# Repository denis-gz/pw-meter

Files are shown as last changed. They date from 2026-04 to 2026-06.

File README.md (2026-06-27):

# PW Meter - EMB_1 Graduation Project

Splash Screen

## Power Meter - An appliance to measure and log AC power line parameters

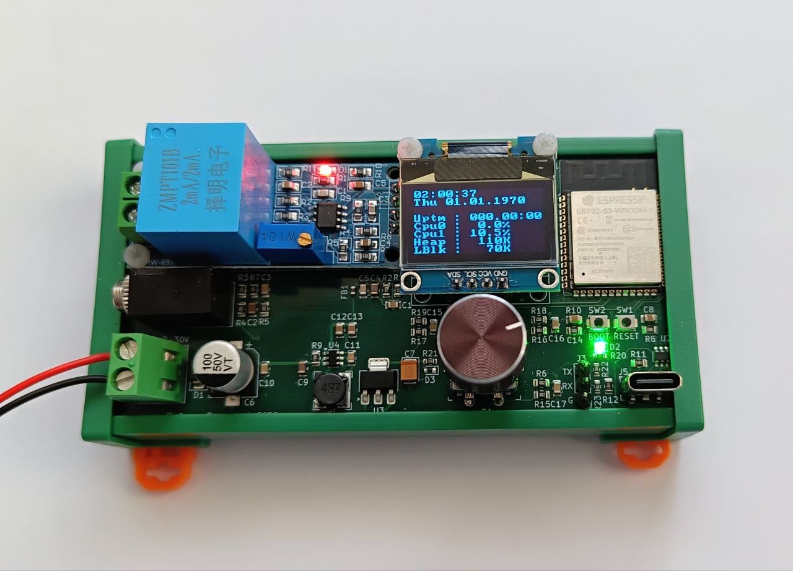
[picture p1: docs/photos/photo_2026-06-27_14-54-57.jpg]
Production sample


The Power Meter can be attached to the AC mains load to measure the following parameters:

 - **AC Voltage** (V, RMS)
 - **AC Current** (A, RMS)
 - **Instantaneous active power** (W)
 - **Instantaneous apparent power** (VA)
 - **Accumulated energy** (Wh)
 - **Power factor** (W/VA ratio)
 - **AC frequency** (Hz)

## Quick Start

In case you have assembled the board using the schematic and components specified in the KiCad project, follow these steps to bring it to life:

1. You may use the supplied firmware image or build your own. If building from source, please update `mqtt_creds.h` and `wifi_creds.h` files with your credentials (not necessary if you do not require MQTT telemetry). Also, please verify settings in the `sdkconfig` to match actual hardware (since at the time of this writing the project has not yet been tested with the actual/final PCB). Use usual `idf.py menuconfig` command to re-generate the `sdkconfig`. See also [defconfig.bak](defconfig.bak) file for exact set of parameters used to configure the project.
2. To build the firmware image, use standard **ESP-IDF** tools (CMake, idf.py, etc). Look [here](https://docs.espressif.com/projects/esp-idf/en/v5.5.4/esp32/api-guides/build-system.html) for a reference.
3. Flash the firmware via USB Serial/JTAG interface (hold the **BOOT** key while powering on the board). The ESP32's **UART0** interface is also available on the **J3** header for flashing or serial console access (useful for adjusting parameters at runtime).
4. Connect the AC voltage source to the Voltage Transformer module (**U6** sub-board).
5. Pass the **Live** wire of the AC load through the core of the Current Transformer (**SCT013-100** or similar). For low-power loads, wrap the wire around the transformer core several times to amplify the signal. Alternatively, use a sensor with a lower current range. If your sensor includes an internal burden resistor, you may need to desolder the **R3** resistor from the board. Connect the Current Transformer to the **J2** socket. It is also possible to use the PW Meter without a load; in this case, set the `I noise floor` parameter high enough to prevent bogus readings.
6. Connect a **7-30V DC** power source to the **J1** socket. The board itself should not consume more than 5 Watts.
7. The Power Meter starts working immediately, displaying data on the OLED display.
8. Use the **Encoder** to switch pages. Use the Encoder's **push-button** to pause/resume on the Mains page, or to enter the menu on the Settings page. Use a **long press** (> 0.5 sec) to return to the upper level. Performing a long press while at the top level will restart the app. Use the **RES** key for a hard reset.

## Project Structure

### Hardware

The project consists of a main board and two sub-boards:
* **Voltage Transformer:** HW-697 Single-phase AC Active Output Voltage Transformer by LC Technology.
* **Display:** SSD1315 128x64 monochrome I2C OLED (GM009605). Any other SSD1306 I2C compatible display should also work (check the module's address in `idf.py menuconfig`).

Sampling of AC voltage and current channels occur in DMA continuous mode, the rate is 4 kHz per channel, with 12 bit resolution and 11.5 dB attenuation. The samples are then adjusted for non-linearity using pre-calibrated curves, centered at 0 level, and processed using DSP capabilities of ESP32-S3 chip. Employing hardware acceleration helps keep CPU usage reasonably low (~10% on Core 1, or only 5% without display output).

Please find further details on project's [Schematic](docs/hardware/Schematic_R1.pdf), and PCB board views ([Top Layer](docs/hardware/PcbTop.png), [Inner 1](docs/hardware/PcbInner1.png), [Inner 2](docs/hardware/PcbInner2.png), [Bottom Layer](docs/hardware/PcbBottom.png) and [3D View](docs/hardware/jlcpcb_3d_1.png)).

### Software

The software consists of 5 tasks:

* `reader_task`: ADC sampling task. Performs reading, parsing and adjustment of analog data. Outputs raw values in mV to a ring buffer for the Compute Task.
* `compute_task`: Processes data in 10-cycle chunks. Performs all mathematical calculations and outputs results to the queue for the Interface Task.
* `interface_task`: Applies filtering, updates the OLED display, handles user input from the rotary encoder and console. Sends a copy of the UI data to the Telemetry Task.
* `telemetry_task`: Maintains Wi-Fi and MQTT connections and publishes data to the MQTT broker.
* `console_input_task`: A service task created by the console event loop that handles prompts and waits for user input from the UART console.

The `PowerMeterApp` class represents the main class which initializes all tasks and waits for a stop event. It handles task shutdown, and the `app_main()` function recreates the instance if needed.

## Signal Path

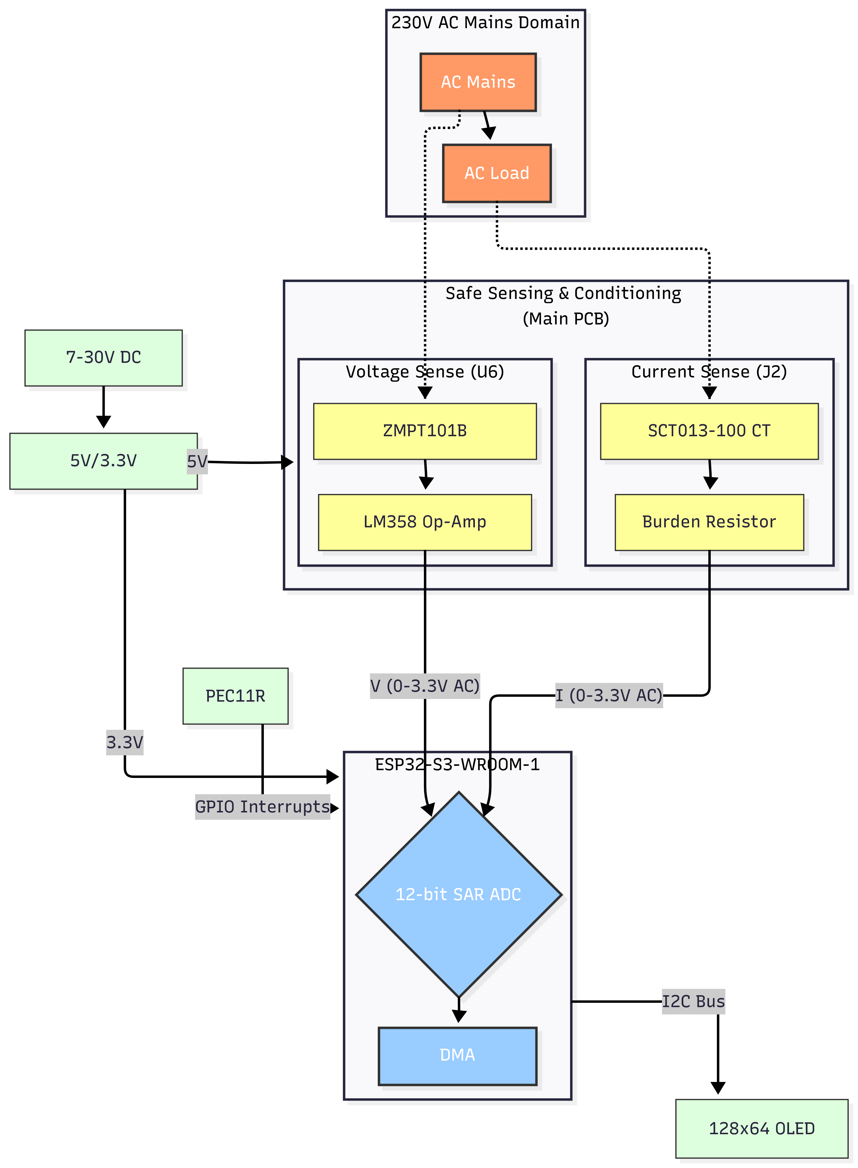
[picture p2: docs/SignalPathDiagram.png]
Signal Path


## Data Flow

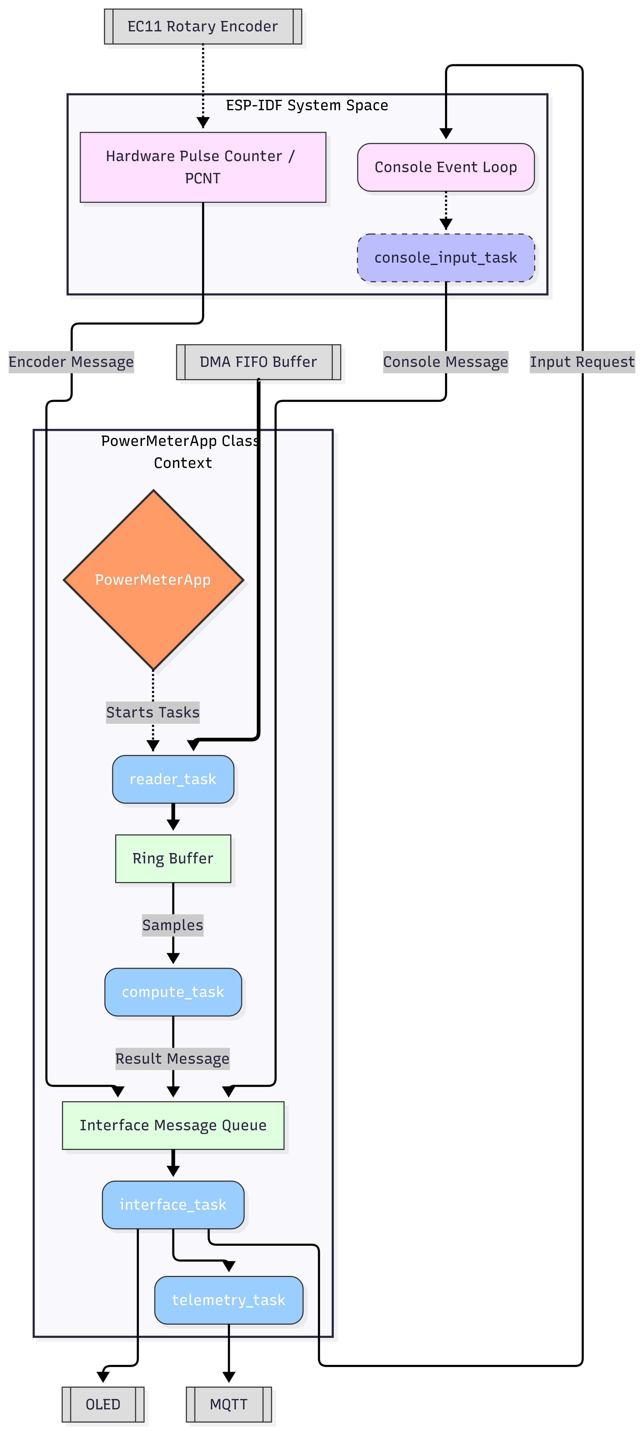
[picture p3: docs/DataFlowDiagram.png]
Data Flow


## Technology

* **MCU:** Espressif ESP32-S3-WROOM-1 N16R2 module
* **AC Voltage Input:** [HW-697](http://www.chinalctech.com/cpzx/Programmer/Sensor_Module/250.html) module by LC Tech (ZMPT101B transformer paired with an LM358 op-amp)
* **AC Current Input:** [SCT013-100](http://en.yhdc.com/comp/file/download.do?id=941) Split-core current transformer (100A, 2000:1 ratio)
* **Display:** GM009605 OLED module based on SSD1306 controller (I2C bus) (or similar)
* **Input:** EC11 rotary encoder
* **Debugging:** BOOT and RESET buttons, UART, and USB Type-C JTAG/Serial ports
* **Software:** ESP-IDF v5.5.4-based CMake project, developed with QtCreator v18.0.2
* **Third-party components:**
    * `nopnop2002/ssd1306`: OLED display support
* **PCB:** 4-layer FR-4 PCB (100x50 mm), developed in KiCad 9.0.7. Mostly uses SMT components (0805 and 0603).

## Example Output

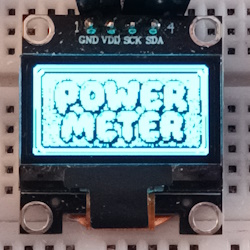
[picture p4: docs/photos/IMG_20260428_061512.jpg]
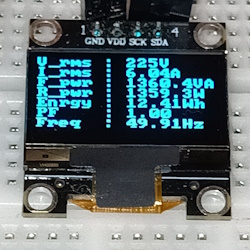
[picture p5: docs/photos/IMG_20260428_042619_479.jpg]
Mains Page
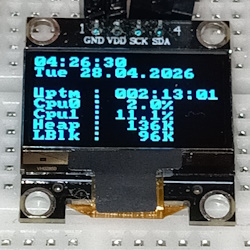
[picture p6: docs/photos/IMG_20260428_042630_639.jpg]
Device Page
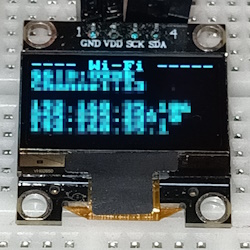
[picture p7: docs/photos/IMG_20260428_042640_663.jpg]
Network Page
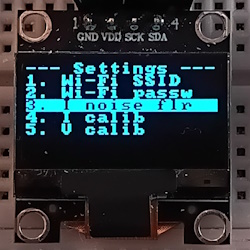
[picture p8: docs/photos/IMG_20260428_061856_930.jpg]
Settings Page
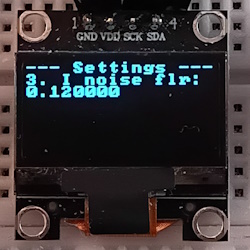
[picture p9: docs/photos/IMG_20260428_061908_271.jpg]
Parameter Page
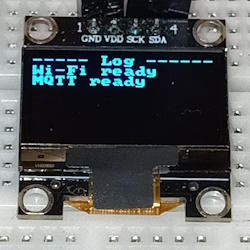
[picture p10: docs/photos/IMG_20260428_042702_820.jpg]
Log Page
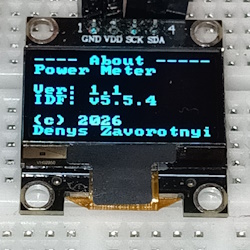
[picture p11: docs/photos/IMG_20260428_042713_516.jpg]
About Page
       

## Author

Copyright © Denys Zavorotnyi, 2026  

## License

[MIT License](LICENSE)

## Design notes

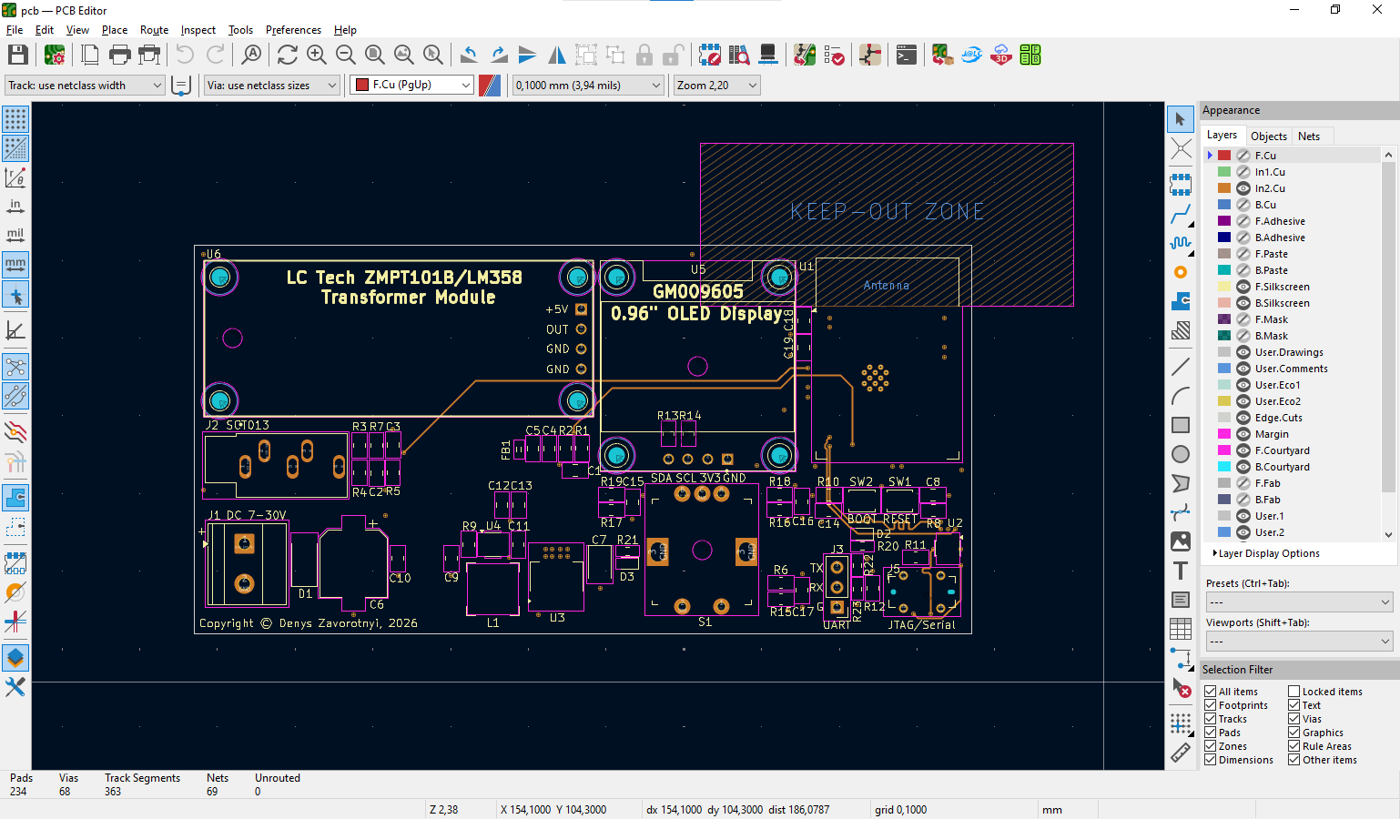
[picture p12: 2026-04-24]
docs/hardware/PcbInner2.png

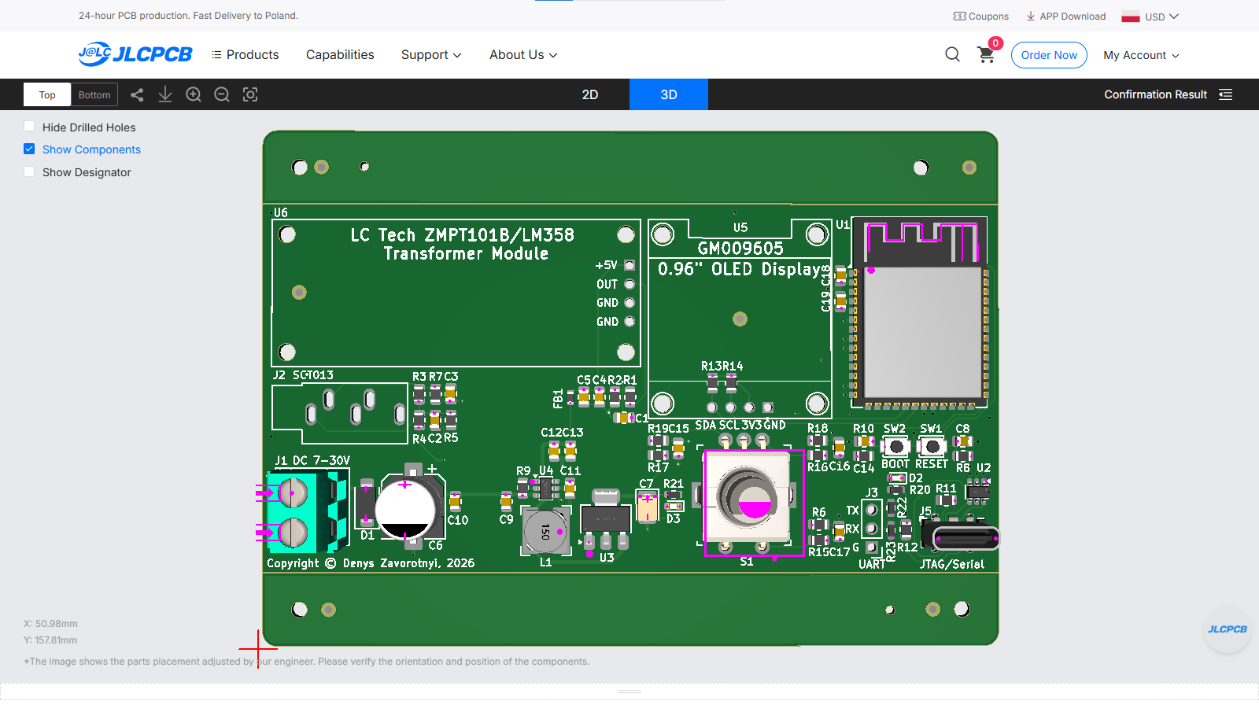
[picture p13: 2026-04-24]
docs/hardware/jlcpcb_3d_4.png

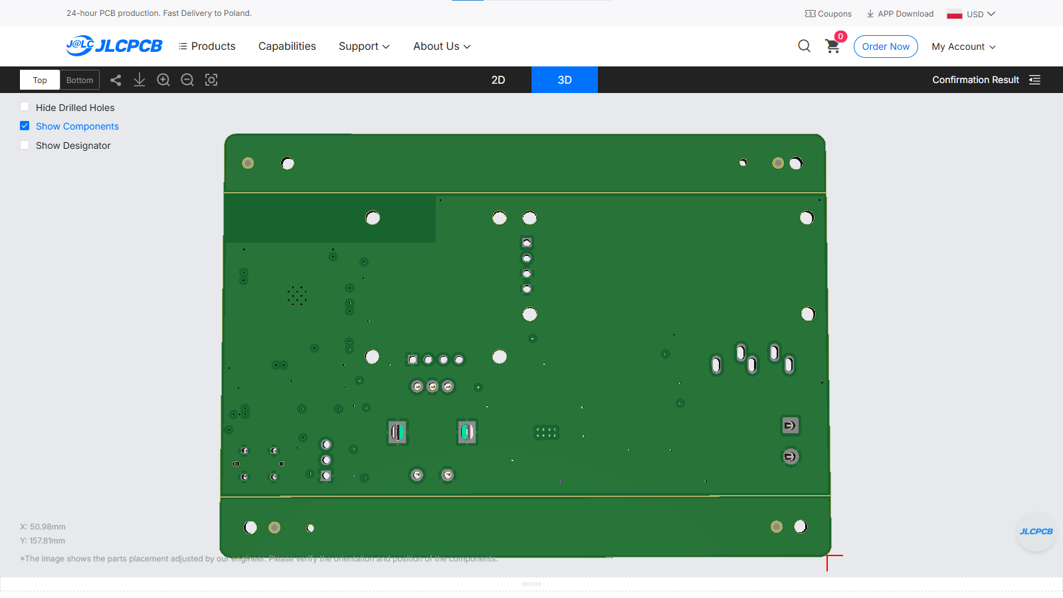
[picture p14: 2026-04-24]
docs/hardware/jlcpcb_3d_3.png

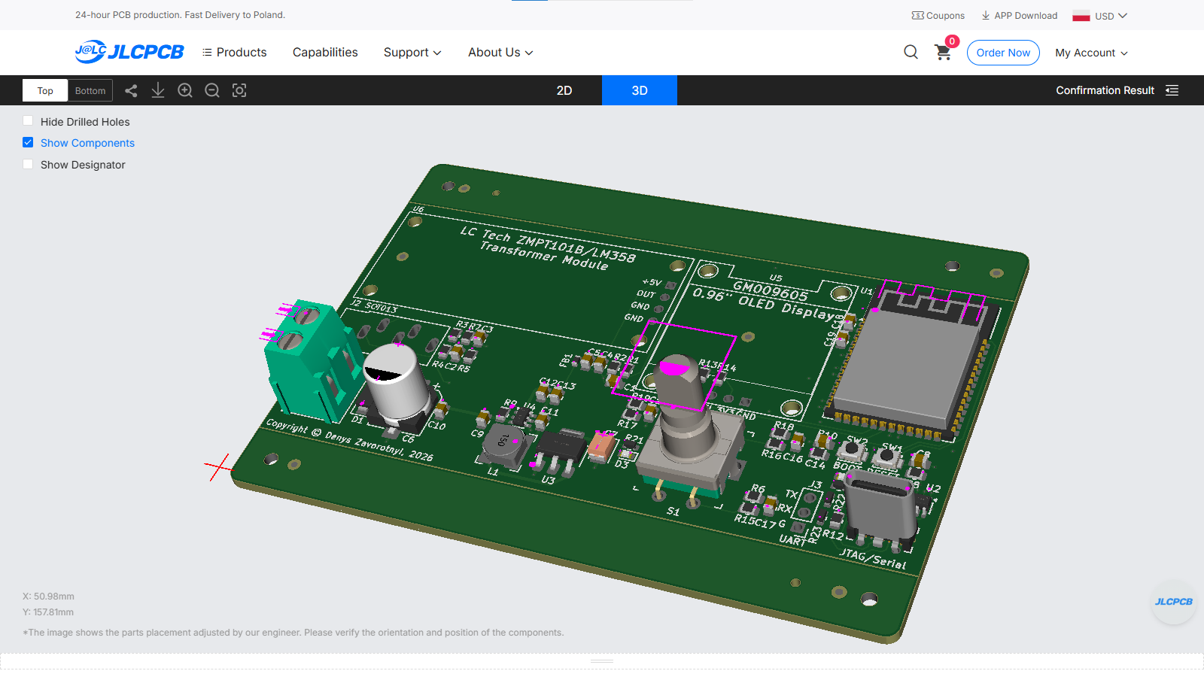
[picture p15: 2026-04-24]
docs/hardware/jlcpcb_3d_1.png

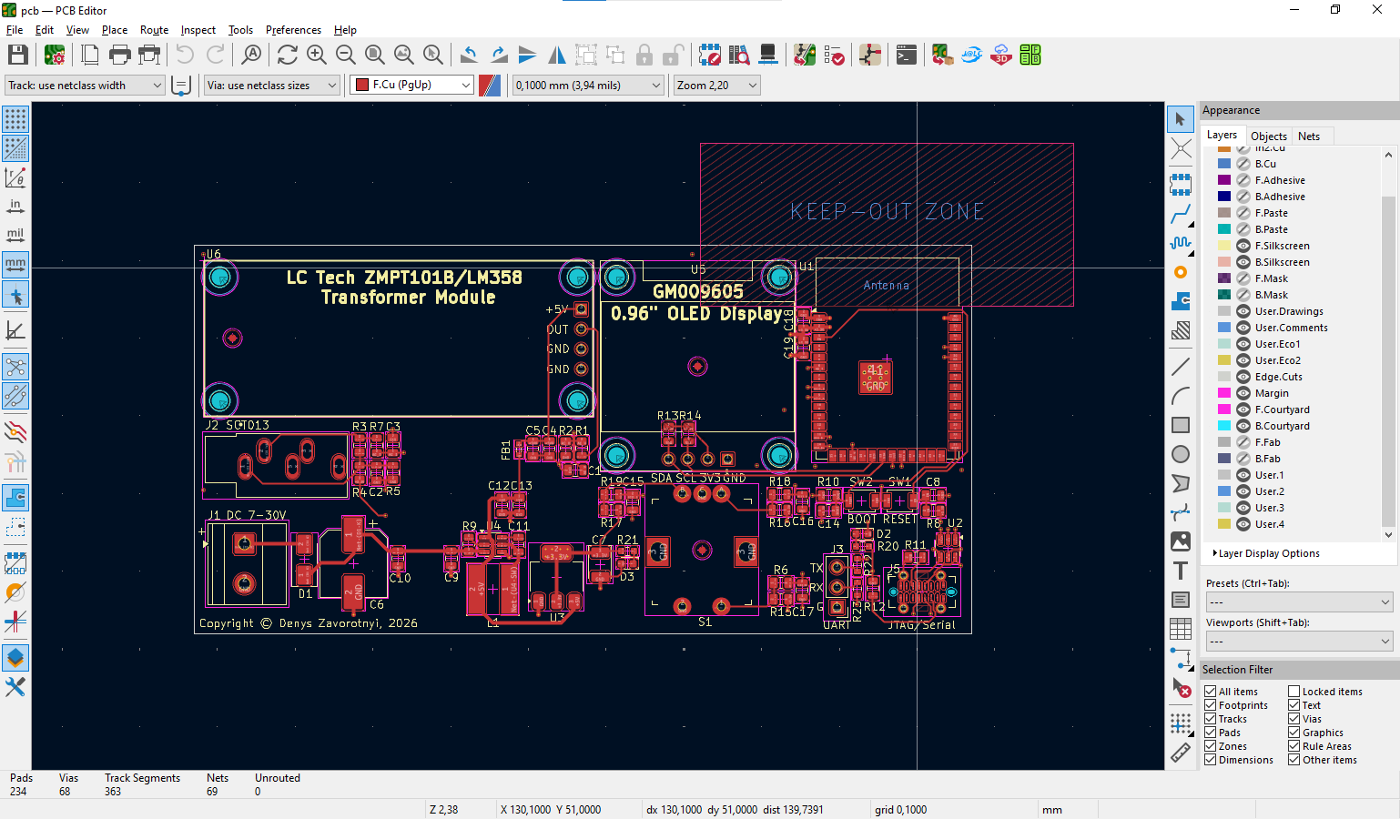
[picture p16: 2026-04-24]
docs/hardware/PcbTop.png

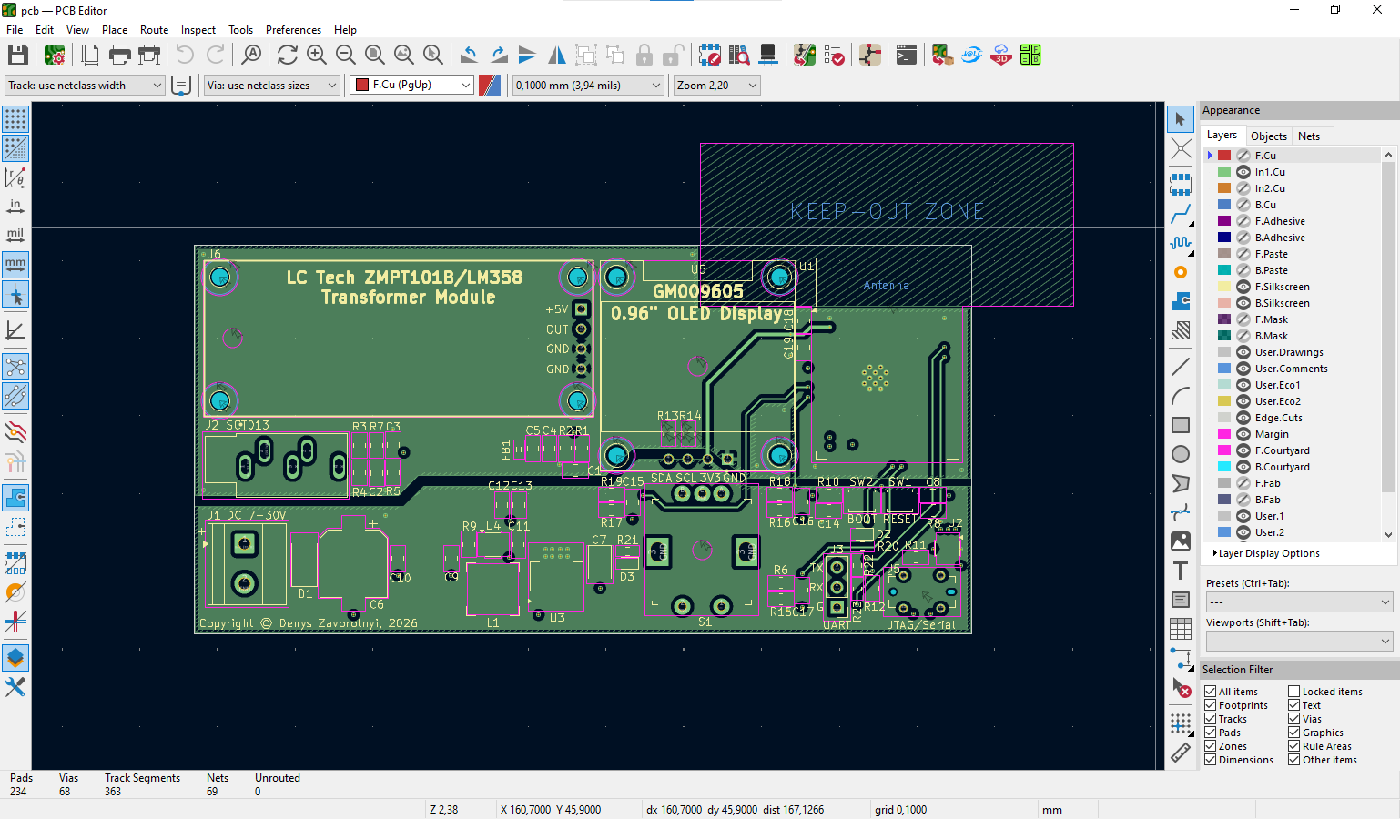
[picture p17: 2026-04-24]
docs/hardware/PcbInner1.png

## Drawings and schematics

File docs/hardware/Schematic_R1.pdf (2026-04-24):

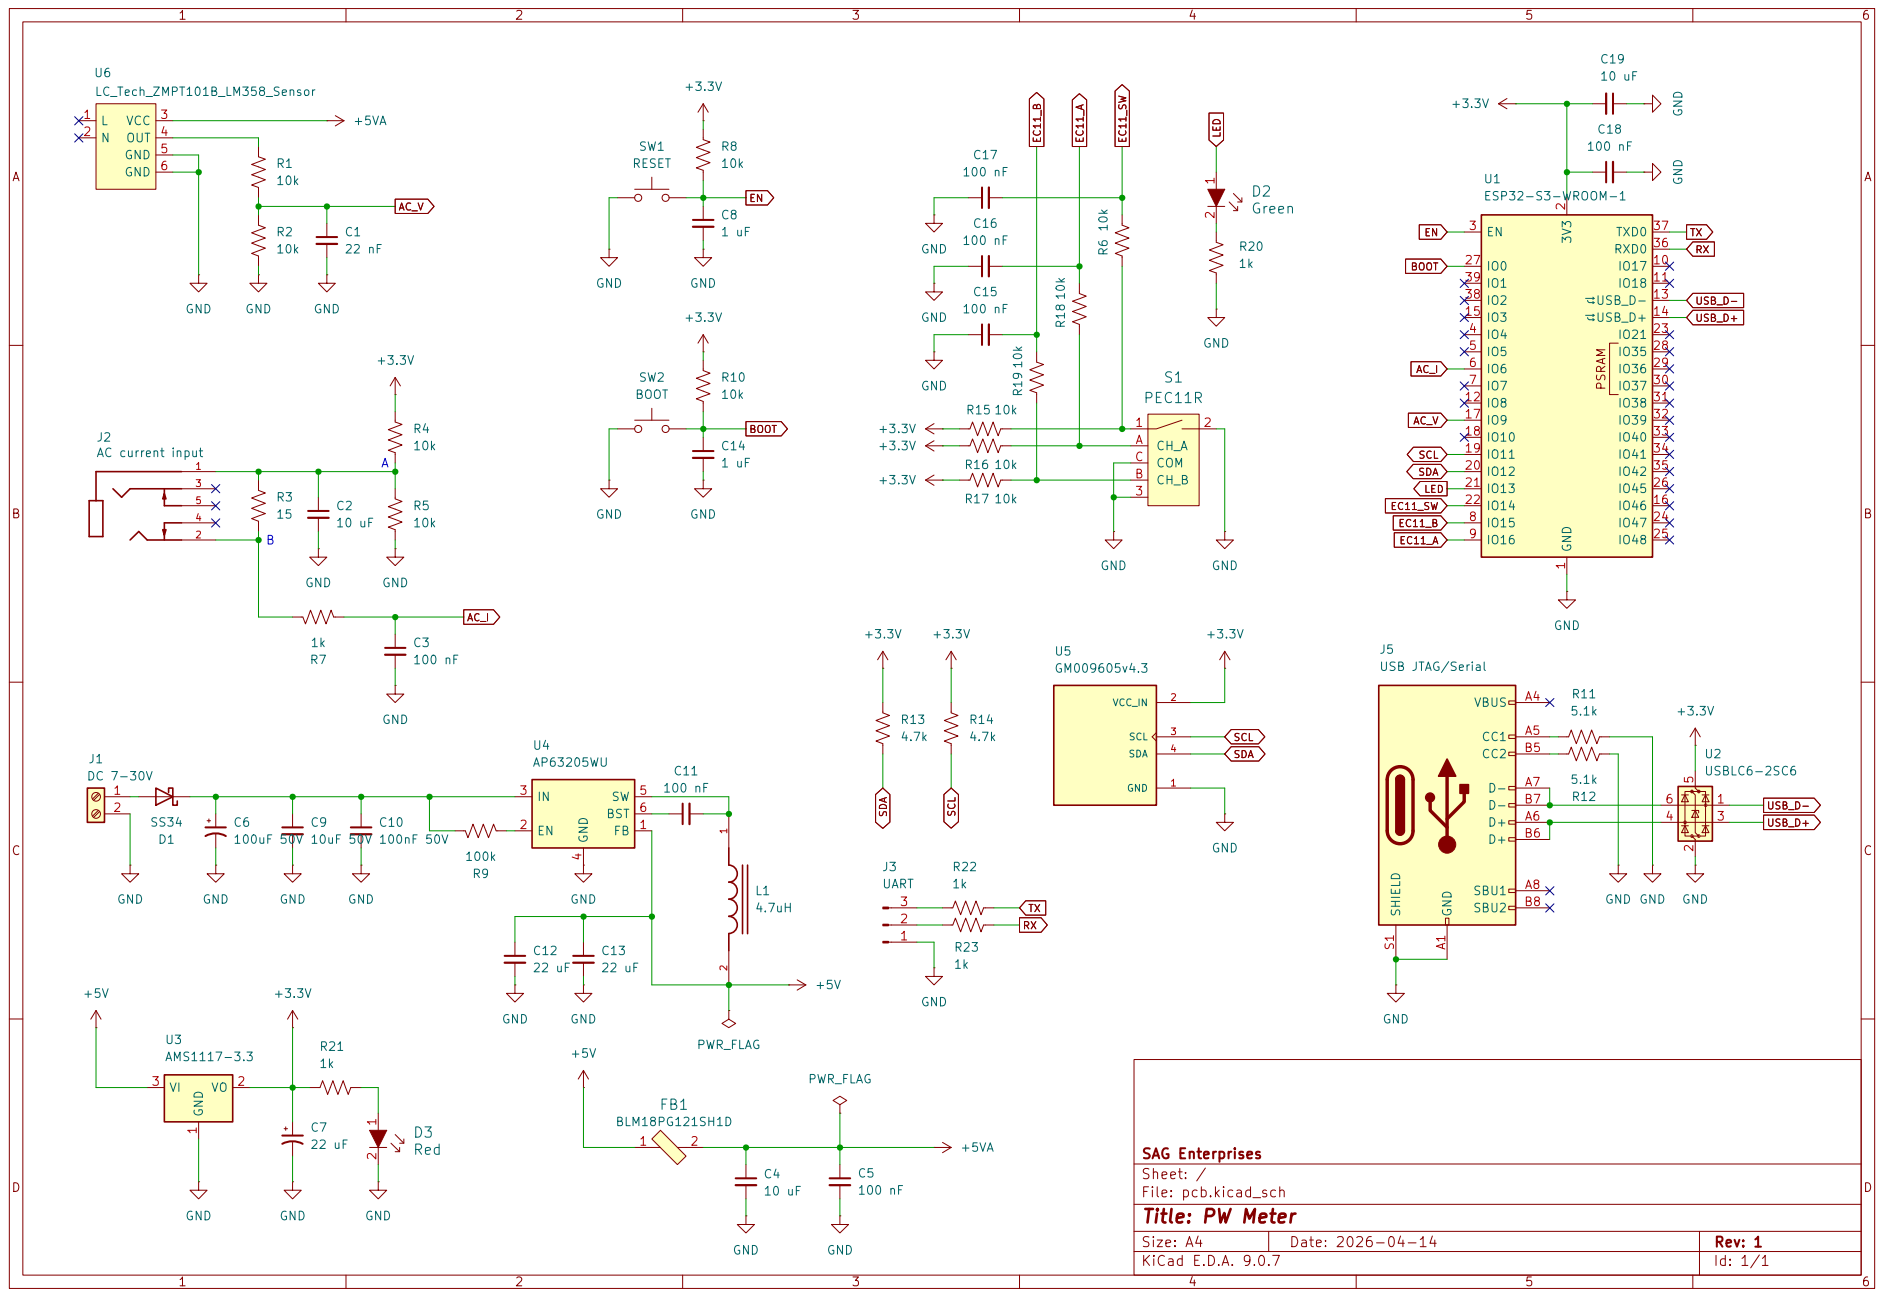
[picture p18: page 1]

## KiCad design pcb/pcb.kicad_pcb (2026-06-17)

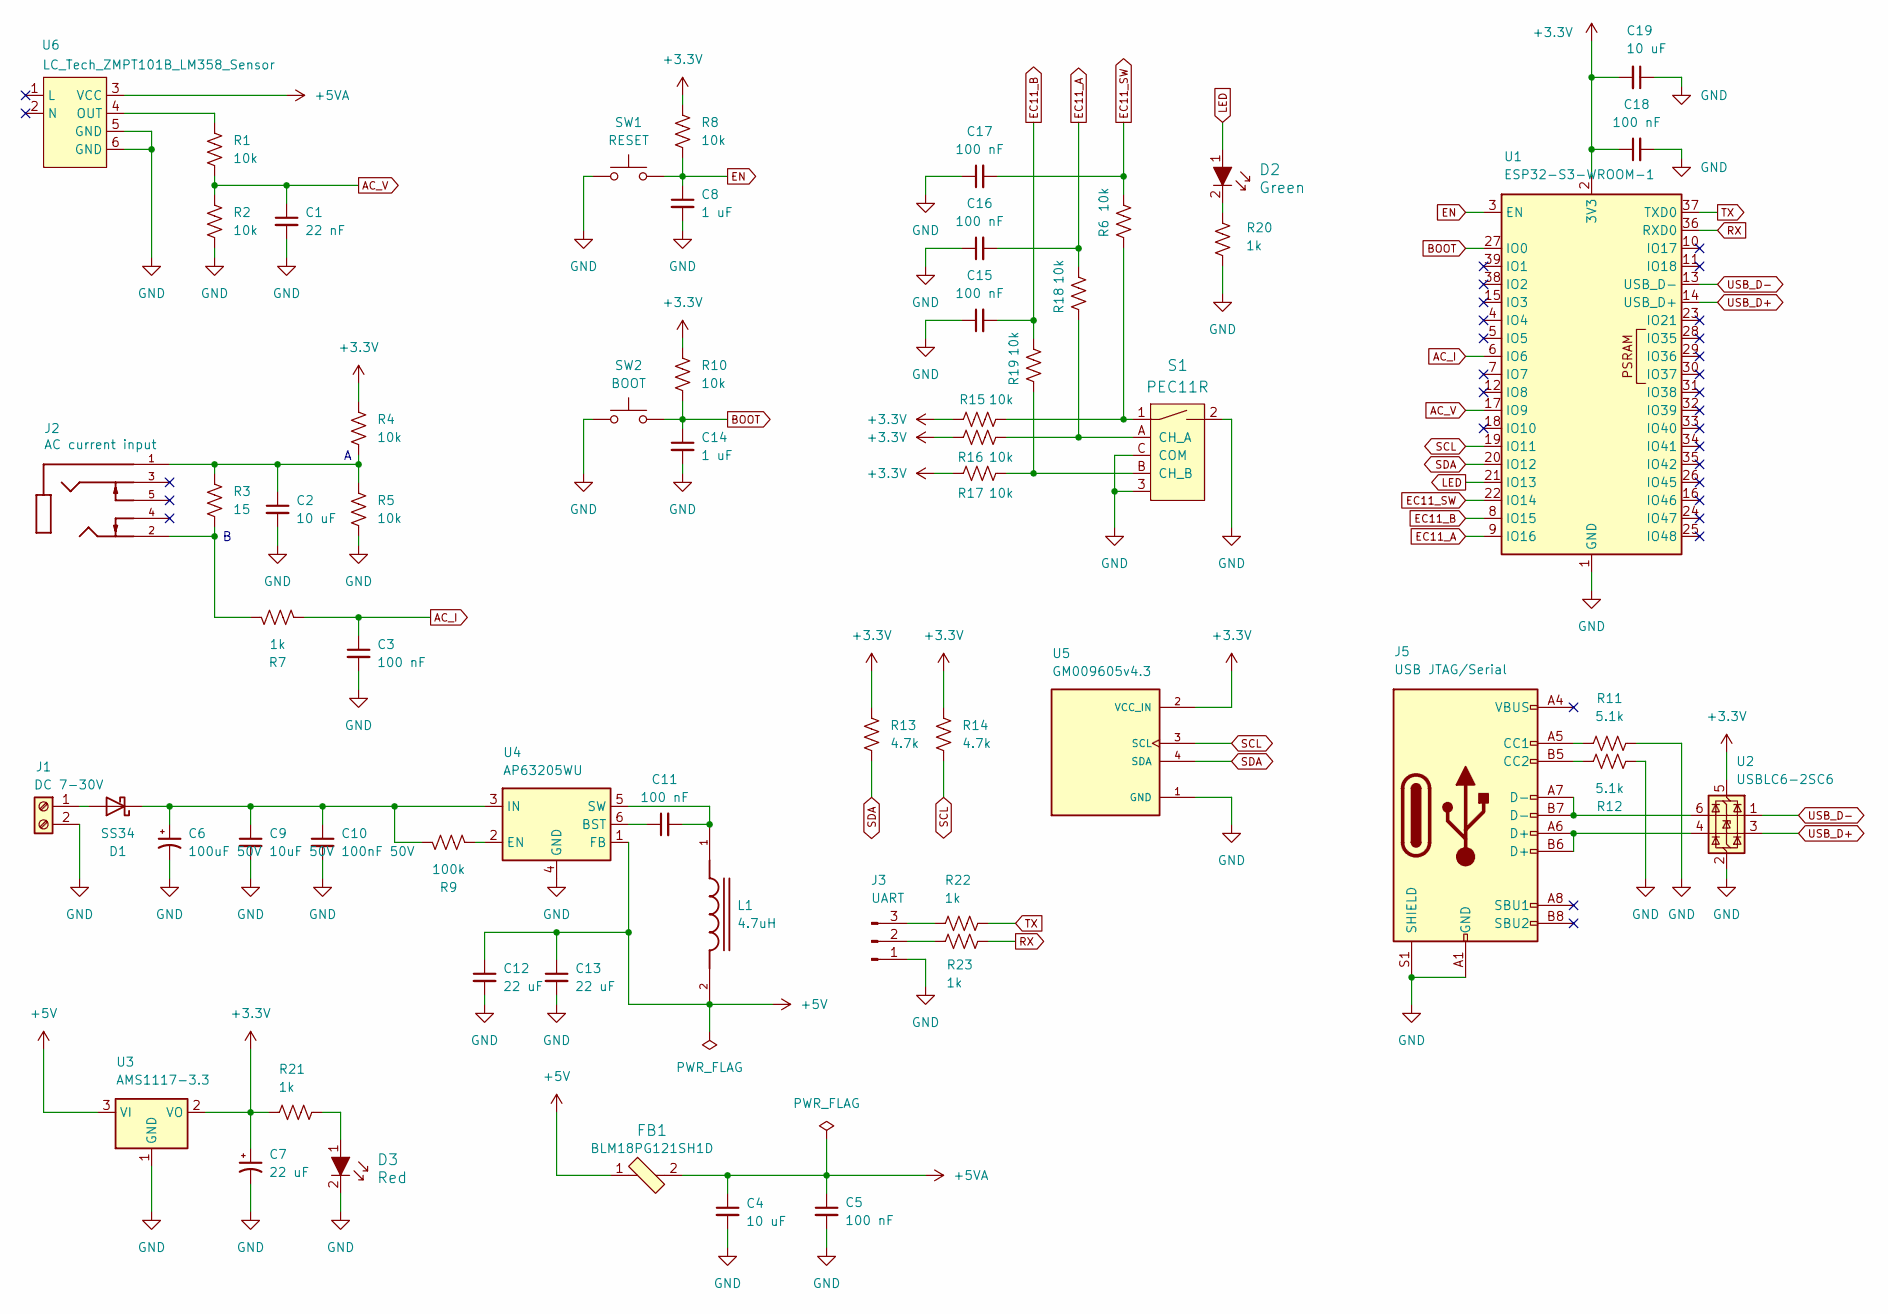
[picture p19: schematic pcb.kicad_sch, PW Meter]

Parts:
C1: 22 nF; C_0805_2012Metric; LCSC C1729
C2, C4, C19: 10 uF; C_0805_2012Metric; LCSC C440198
C3, C5, C11, C15, C16, C17, C18: 100 nF; C_0805_2012Metric; LCSC C49678
C6: 100uF 50V; CP_Elec_8x10.5; LCSC C970687
C7: 22 uF; CP_EIA-3528-21_Kemet-B; LCSC C1953099
C8, C14: 1 uF; C_0805_2012Metric; LCSC C28323
C9: 10uF 50V; C_0805_2012Metric; LCSC C440198
C10: 100nF 50V; C_0805_2012Metric; LCSC C49678
C12, C13: 22 uF; C_0805_2012Metric; LCSC C45783
D1: SS34; D_SMA; LCSC C8678
D2: Green; LED_0603_1608Metric; MPN KT-0603G; LCSC C12624
D3: Red; LED_0603_1608Metric; MPN KT-0603R; LCSC C2286
FB1: BLM18PG121SH1D; 0603; MPN BLM18PG121SN1D; Digi-Key_PN 490-1037-1-ND
J1: DC 7-30V; TerminalBlock_Phoenix_MKDS-1,5-2-5.08_1x02_P5.08mm_Horizont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; LCSC C5183929
J2: AC current input; XKB_PJ-325C5-G; PARTREV A0
J3: UART; PinHeader_1x03_P2.54mm_Vertical
J5: USB JTAG/Serial; USB_C_Receptacle_G-Switch_GT-USB-7051x; LCSC C2843970
L1: 4.7uH; L_SXN-SDRH5D28; LCSC C26382
R1, R2, R4, R5, R6, R8, R10, R15, R16, R17, R18, R19: 10k; R_0805_2012Metric; LCSC C17414
R3: 15; R_0805_2012Metric; LCSC C17480
R7: 1k; R_0805_2012Metric; LCSC C17513
R9: 100k; R_0805_2012Metric; LCSC C149504
R11, R12: 5.1k; R_0805_2012Metric; LCSC C27834
R13, R14: 4.7k; R_0805_2012Metric; LCSC C17673
R20, R21, R22, R23: 1k; R_0603_1608Metric; LCSC C21190
S1: PEC11R; Rotary_Encoder_Switched_PEC11R; MPN PEC11R-4215F-S0024; Digi-Key_PN PEC11R-4215F-S0024-ND
SW1: RESET; SW_SPST_B3U-1000P; LCSC C231329
SW2: BOOT; SW_SPST_B3U-1000P; LCSC C231329
U1: ESP32-S3-WROOM-1; LCSC C2913202
U2: USBLC6-2SC6; SOT-23-6; LCSC C7519
U3: AMS1117-3.3; SOT-223-3_TabPin2; LCSC C6186
U4: AP63205WU; TSOT-23-6; LCSC C2071056
U5: GM009605v4.3; MODULE_GM009605v4.3; PARTREV 2018-09-10
U6: LC_Tech_ZMPT101B_LM358_Sensor

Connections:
+3.3V: C7.1, C18.1, C19.2, R4.1, R8.1, R10.1, R13.1, R14.1, R15.1, R16.1, R17.1, R21.1, U1.2 (3V3), U2.5 (VBUS), U3.2 (VO), U5.2 (VCC_IN)
+5V: C12.1, C13.1, FB1.1, L1.2, U3.3 (VI), U4.1 (FB)
+5VA: C4.1, C5.1, FB1.2, U6.3 (VCC)
AC_I: C3.1, R7.2, U1.6 (IO6)
AC_V: C1.1, R1.2, R2.1, U1.17 (IO9)
BOOT: C14.1, R10.2, SW2.2 (B), U1.27 (IO0)
EC11_A: C16.2, R18.2, U1.9 (IO16)
EC11_B: C15.2, R19.2, U1.8 (IO15)
EC11_SW: C17.2, R6.2, U1.22 (IO14)
EN: C8.1, R8.2, SW1.2 (B), U1.3 (EN)
GND: C1.2, C2.2, C3.2, C4.2, C5.2, C6.2, C7.2, C8.2, C9.2, C10.2, C12.2, C13.2, C14.2, C15.1, C16.1, C17.1, C18.2, C19.1, D3.2, J1.2, J3.1, J5.A1 (GND), J5.A12 (GND), J5.B1 (GND), J5.B12 (GND), J5.S1 (SHIELD), R2.2, R5.2, R11.2, R12.1, R20.2, S1.2, S1.3, S1.C (COM), SW1.1 (A), SW2.1 (A), U1.1 (GND), U1.40 (GND), U1.41 (GND), U2.2 (GND), U3.1 (GND), U4.4 (GND), U5.1 (GND), U6.5 (GND), U6.6 (GND)
LED: D2.1, U1.21 (IO13)
unnamed: C2.1, J2.1, R3.1, R4.2, R5.1
unnamed: D1.2 (A), J1.1
unnamed: C6.1, C9.1, C10.1, D1.1 (K), R9.1, U4.3 (IN)
unnamed: D2.2, R20.1
unnamed: D3.1, R21.2
unnamed: J2.2, R3.2, R7.1
unnamed: J3.2, R23.2
unnamed: J3.3, R22.1
unnamed: J5.A5 (CC1), R11.1
unnamed: J5.B5 (CC2), R12.2
unnamed: J5.A6 (D+), J5.B6 (D+), U2.4 (I/O2)
unnamed: J5.A7 (D-), J5.B7 (D-), U2.6 (I/O1)
unnamed: R6.1, R15.2, S1.1
unnamed: R16.2, R18.1, S1.A (CH_A)
unnamed: R17.2, R19.1, S1.B (CH_B)
unnamed: C11.1, U4.6 (BST)
unnamed: R9.2, U4.2 (EN)
unnamed: C11.2, L1.1, U4.5 (SW)
unnamed: R1.1, U6.4 (OUT)
RX: R23.1, U1.36 (RXD0)
SCL: R14.2, U1.19 (IO11), U5.3 (SCL)
SDA: R13.2, U1.20 (IO12), U5.4 (SDA)
TX: R22.2, U1.37 (TXD0)
USB_D+: U1.14 (USB_D+), U2.3 (I/O2)
USB_D-: U1.13 (USB_D-), U2.1 (I/O1)

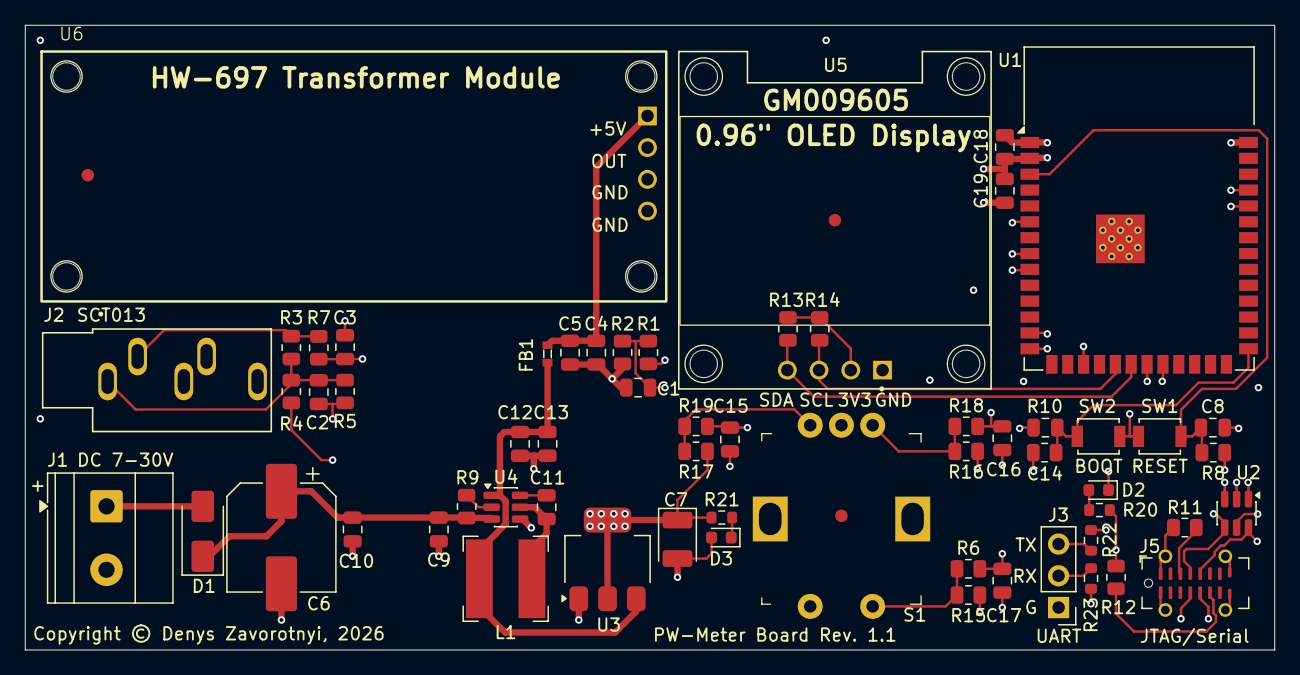
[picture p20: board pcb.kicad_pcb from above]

Board: 4 copper layers, 100.0 x 50.0 mm, 60 parts (0 on the bottom side), 37 nets.

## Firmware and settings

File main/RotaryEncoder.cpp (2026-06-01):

#include "RotaryEncoder.h"

#include <freertos/FreeRTOS.h>
#include <driver/gpio.h>
#include <esp_log.h>

#include "common.h"

RotaryEncoder::RotaryEncoder(int pin_A, int pin_B, std::function<void(bool)> on_rotate)
{
    m_callback = on_rotate;

    pcnt_unit_config_t pcnt_unit_config = {
        .low_limit = -1,
        .high_limit = 1,
        .flags { .accum_count = 1 },
    };
    ESP_ERROR_CHECK(pcnt_new_unit(&pcnt_unit_config, &m_unit));

    pcnt_event_callbacks_t cbs = { .on_reach = pcnt_watch_callback };
    ESP_ERROR_CHECK(pcnt_unit_register_event_callbacks(m_unit, &cbs, this));
    ESP_ERROR_CHECK(pcnt_unit_add_watch_point(m_unit, -1));
    ESP_ERROR_CHECK(pcnt_unit_add_watch_point(m_unit, 1));

    pcnt_glitch_filter_config_t pcnt_glitch_config = { .max_glitch_ns = 7500 };
    ESP_ERROR_CHECK(pcnt_unit_set_glitch_filter(m_unit, &pcnt_glitch_config));

    ESP_ERROR_CHECK(gpio_pullup_en(static_cast<gpio_num_t>(pin_B)));
    ESP_ERROR_CHECK(gpio_pullup_en(static_cast<gpio_num_t>(pin_B)));

    pcnt_chan_config_t pcnt_chan_config = {
        .edge_gpio_num = pin_A,
        .level_gpio_num = pin_B,
    };
    ESP_ERROR_CHECK(pcnt_new_channel(m_unit, &pcnt_chan_config, &m_chan));

    ESP_ERROR_CHECK(pcnt_channel_set_edge_action(m_chan, PCNT_CHANNEL_EDGE_ACTION_INCREASE, PCNT_CHANNEL_EDGE_ACTION_HOLD));
    ESP_ERROR_CHECK(pcnt_channel_set_level_action(m_chan, PCNT_CHANNEL_LEVEL_ACTION_KEEP, PCNT_CHANNEL_LEVEL_ACTION_INVERSE));

    ESP_ERROR_CHECK(pcnt_unit_enable(m_unit));
}

RotaryEncoder::~RotaryEncoder()
{
    pcnt_unit_disable(m_unit);
    pcnt_del_channel(m_chan);
    pcnt_del_unit(m_unit);
}

void RotaryEncoder::Start()
{
    pcnt_unit_start(m_unit);
}

void RotaryEncoder::Stop()
{
    pcnt_unit_stop(m_unit);
}

void RotaryEncoder::ResetCounter()
{
    pcnt_unit_clear_count(m_unit);
}

int RotaryEncoder::Counter() const
{
    int counter = 0;
    pcnt_unit_get_count(m_unit, &counter);
    return counter;
}


bool IRAM_ATTR RotaryEncoder::pcnt_watch_callback(pcnt_unit_handle_t unit, const pcnt_watch_event_data_t* edata, void* user_ctx)
{
    auto& _ = *static_cast<RotaryEncoder*>(user_ctx);

    int counter = 0;
    pcnt_unit_get_count(unit, &counter);
    _.m_callback(counter > _.m_counter);
    _.m_counter = counter;

    return false;
}

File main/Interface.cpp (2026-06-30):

#include "PowerMeterApp.h"

#include "Filters.h"
#include "../resources/SplashScreen_PowerMeter_128x64.h"
#include <list>

#include <esp_wifi.h>
#include <esp_ota_ops.h>
#include "pin_creds.h"

static const std::array<uint8_t, 4> SETTINGS_PIN = DEVICE_PIN;

#define READINGS_PER_SECOND 5

enum ScreenPage: uint8_t {
    SplashScreen,
    MainsPage,
    DevicePage,
    SettingsPage,
    LogPage,
    AboutPage,

    PageCount
};

enum InputState {
    PageSelection,
    PinInput,
    MenuSelection,
    ItemDisplay,
    ValueInput,
};

enum MenuItem {
    ItemNone = -1,
    ItemWifiSsid,
    ItemWifiPassword,
    ItemWifiInfo,
    ItemMqttUri,
    ItemMqttCreds,
    ItemMqttTopic,
    ItemMqttPeriod,
    ItemINoiseFloor,
    ItemICalib,
    ItemVCalib,
    ItemVEnergySave,
    ItemResetEnrgy,

    ItemCount,
    ItemDefault = ItemWifiSsid,
};

static const int N_DISPLAYED_ITEMS = 7;

static constexpr const char MENU_ITEMS[ItemCount][16] {
    { "1. Wi-Fi SSID" },
    { "2. Wi-Fi passw" },
    { "3. Wi-Fi info" },
    { "4. MQTT URI" },
    { "5. MQTT creds" },
    { "6. MQTT topic" },
    { "7. MQTT period" },
    { "8. I noise flr" },
    { "9. I calib" },
    { "10. V calib" },
    { "11. V nrgy save" },
    { "12. Reset enrgy" }
};

struct DisplayContext
{
    using Filter = AdaptiveDisplayFilter;

    Filter filter_v { 20 };
    Filter filter_i { 0.5 };
    Filter filter_w { 10 };
    // Filter filter_pf{ 0.1 };
    Filter filter_hz{ 0.1 };
    // Filter filter_sh{ 0.3 };

    bool with_display = false;
    bool is_display_awake = true;
    TickType_t last_interaction_tick = 0;

    uint32_t counter = 0;
    uint32_t pause = 0;

    display_line_t lines[8] {};     // Display matrix is 16x8 chars
    int inverse[8] {};              // Inversion flags for each line

    std::list<display_line_t> log;

    ScreenPage page {};
    InputState input_state {};
    MenuItem item_selected {};
    uint8_t first_displayed_menu_item = 0;
    PowerMeterApp::MqttMessage::DeviceMetrics dev {};

    bool settings_unlocked = false;
    std::array<uint8_t, std::size(SETTINGS_PIN)> pin_digits {};
    uint8_t pin_index = 0;

    void clear_screen(bool clear_inverse = true) {
        memset(lines, 0x20, sizeof(lines));
        if (clear_inverse)
            memset(inverse, 0, sizeof(inverse));
    }

    void set_next_page() {
        page = (ScreenPage) ((page + 1) % PageCount);
        if (page == SplashScreen)
            page = (ScreenPage) (SplashScreen + 1);
    }

    void set_prev_page() {
        page = (ScreenPage) ((page + PageCount - 1) % PageCount);
        if (page == SplashScreen)
            page = (ScreenPage) (PageCount - 1);
    }

    void set_next_item() {
        item_selected = (MenuItem) ((item_selected + 1) % ItemCount);
        update_viewport();
    }

    void set_prev_item() {
        item_selected = (MenuItem) ((item_selected + ItemCount - 1) % ItemCount);
        update_viewport();
    }

    void update_viewport() {
        if (first_displayed_menu_item > item_selected)
            first_displayed_menu_item = item_selected;
        else if (first_displayed_menu_item < item_selected - N_DISPLAYED_ITEMS + 1)
            first_displayed_menu_item = item_selected - N_DISPLAYED_ITEMS + 1;
        lines[0].fill(0x20);    // Invalidate the page
    }
};

static DisplayContext ds;

void PowerMeterApp::setup_interface(bool disposing)
{
    if (disposing) {
        m_encoder.Stop();

        if (ds.with_display) {
            ssd1306_clear_screen(&m_oled, false);
        }
        if (m_oled._i2c_dev_handle) {
            i2c_master_bus_rm_device(m_oled._i2c_dev_handle);
            m_oled._i2c_dev_handle = nullptr;
        }
        if (m_oled._i2c_bus_handle) {
            i2c_del_master_bus(m_oled._i2c_bus_handle);
            m_oled._i2c_bus_handle = nullptr;
        }
        vQueueDelete(m_interface_queue), m_interface_queue = nullptr;
    }
    else {
        ESP_LOGI(TAG, "interface setup");
        m_interface_queue = xQueueCreate(10, sizeof(InterfaceTaskMessage));

        i2c_master_init(&m_oled, CONFIG_SDA_GPIO, CONFIG_SCL_GPIO, CONFIG_RESET_GPIO);
        m_led.init();

        int retries = 5;
        esp_err_t res;

        while (retries--) {
            res = ssd1306_init(&m_oled, 128, 64);
            if (res == ESP_OK)
                break;
            ESP_LOGI(TAG, "Retrying in 50 msec...");
            vTaskDelay(pdMS_TO_TICKS(50));
        }

        if (res == ESP_OK) {
            ssd1306_clear_screen(&m_oled, false);
            ssd1306_contrast(&m_oled, 0x7F);
            ssd1306_bitmaps(&m_oled, 0, 0, SPLASH_SCREEN, 128, 64, false);

            // Delay before displaying results to let splash screen linger for some time
            ds.pause = 8;   // 8 * 0.2 = 1.6 sec
            ds.with_display = true;
        }
        else {
            ESP_LOGI(TAG, "Working without display output");
        }

        m_encoder.Start();
    }
}
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

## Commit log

2026-04-24 Revision 1
    [pcb.kicad_pcb, pcb.kicad_sch]
2026-04-25 Work in progress:
    - Fixed V/A alignment logic to have more precise power estimation
    - Fixed SSD1306 and I2C initialization
    - Refactoring
    [Button.cpp, Compute.cpp, PowerMeterApp.cpp]
2026-04-26 Version 1.1
    - Added Wi-Fi connectivity
    - Added telemetry task (MQTT reporting)
    - Added Device info, Network info, Log and About pages
    - Added splash screen
    - Fixed button long click
    - Fixed regular frequency spikes
    - Changed sampling to 4 kHz per channel
    - Added small hysteresis to sine wave zero crossing detection
    - Massive refactoring
    [Button.cpp, Compute.cpp, PowerMeterApp.cpp]
2026-04-28 Implemented console input to allow entering new values of settings
    - Bug fixes and refactoring
    [Compute.cpp, Interface.cpp, PowerMeterApp.cpp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]
2026-04-28 Added Data Flow / Signal Path diagrams
2026-04-28 Fixed Wi-Fi settings not being applied
    [Interface.cpp]
2026-04-29 Bug fixes and refactoring
    [Button.cpp, Compute.cpp, Interface.cpp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]
2026-06-01 Updated GPIO configuration for production PCB
    - A bit of refactoring
2026-06-01 Improved measurements reporting:
    - Increased voltage display precision to 0.1V
    - Added frequency invalidation on voltages below 5VAC (disconnected/blackout state actually) to avoid bogus readings
    [Interface.cpp]
2026-06-02 Updated schematic (non-functional)
    [pcb.kicad_sch]
2026-06-02 Improved parameters stability, esp. AC frequency
    - Added detection of voltage spikes in ADC readings (often caused by OLED interference)
    [Compute.cpp, Interface.cpp, Reader.cpp]
2026-06-02 UI improvements:
    - Status LED logic extended to display following state:
    1. Wi-Fi searching (0.5 sec blinks, permanent mode)
    2. Wi-Fi connection and IP assignment (steady on, permanent mode)
    3. MQTT transmittion (single blink, transient mode)
    4. MQTT error (three blinks, transient mode)
    - System uptime now displays time in Days.Hours:Minutes format (upto 999 days, then invalidates)
    - Warnings fixed
    [Interface.cpp, LED.cpp, PowerMeterApp.cpp]
2026-06-02 Changed UART0 speed to 921600 bps
2026-06-17 PCB updated:
    Revision 1.1
    - Corrected footprint of the LC Tech HW-697 module
    - Moved HW-697 signal output track to the In2.Cu layer
    Previous updates:
    - Justified length of the USB D+/D- tracks
    [pcb.kicad_pcb]
2026-06-18 Work in progress:
    - Fixed AC frequency measurement error caused by inaccuracies of ADC clock
    - Fixed reporting of reversed EC11 encoder rotation after replacing it with a better quality part
    - Changed schematic (R1: 10k -> 4.7k) to allow more utilization of available ADC range while
    using lesser level of HW-697 hardware attenuation. This helps prevent AC_V sine wave clipping
    caused by LM358 saturation at 3.5V
    - Temporary switched to a forked esp-idf-ssd1306 repository until my PR is merged to the upstream
    - Added Max and Min readings of AC_V and AC_I channels at startup (debugging console)
    - Display filters tweak (more latency)
    - Removed fractional part from AC Voltage display (doesn't h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
    [pcb.kicad_sch]
2026-06-22 Added display sleep on 1 min encoder input timeout (push to awake)...
    ... - this prevents OLED burnout and reduces ADC noise at the same time
    [Interface.cpp]
2026-06-22 Added PIN-code protection for Settings:
    - Enter with encoder
    - 4-digits hard-coded
    - Invalidated on screen sleep
2026-06-30 Version 1.4:
    - Refactored Settings menu, fixed bugs, implemented scrolling, added new items:
    - MQTT broker settings (URI, creds, topic, reporting interval)
    - Voltage threshold for energy counter backup to NVS (counter is saved when
    voltage drops below threshold)
    - A menu item to reset energy counter
    - Added MQTT topic to report device status (cpu, memory, uptime)
    - Changed MQTT reporting to issue JSON structure per two sub-topics: "power" and "device",
    appended to configured common topic
    [Interface.cpp, PowerMeterApp.cpp]
2026-06-30 Updated schematic version, added copytight
    [pcb.kicad_sch]
2026-07-02 Added 'v_noise_floor' setting
    - This version along with device is deployed to actual service
2026-10-18 Version 1.5
    esp-idf: framework updated to v5.5.6
    firmware: robust frequency filter, dynamic ADC sampling rate measurement, and cycle-synced RMS calcs
    - Implemented dynamic ADC DMA sampling frequency calibration using esp_timer (40 MHz XTAL reference) to track actual Fs drift dynamically (initialized with 4006.0 Hz hardware baseline)
    - Added MedianEMAFilter (5-point median filter + EMA) to eliminate zero-crossing switching spikes and transient needles while preserving responsiveness for genset diagnostics
    - Updated zero-crossing detector to support a 15–65 Hz range for genset diagnostics
    - Implemented cycle-synchronized RMS and power calculations over an exact integer number of AC cycles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
2026-10-21 [firmware] surgical RF despiking, overvoltage pass-through, and monotonic energy integration
    - Replaced full-chunk rejection on RF transients with in-place surgical sample interpolation (1..5 samples) to prevent data loss and avoid corrupting DCBlocker bias estimates;
    - Allowed sustained AC overvoltage waveforms (> 5 samples above nominal threshold) to pass through unimpeded so phase-to-phase/neutral-loss grid faults up to the physical ADC ceiling are accurately measured and reported;
    - Switched energy accumulation from theoretical chunk duration to monotonic hardware timer deltas (esp_timer_get_time) to eliminate Watt-hour drift across buffer hiccups or task scheduling jitter;
    - Tightened p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
2026-10-22 Bug fixes and build configuration cleanup
    - [firmware] fixed possible crash in input ISRs during flash operations
    - [firmware] fixed uptime: counted from boot instead of first SNTP sync, fixed hours display
    - [firmware] fixed integer console input parsing: strtol instead of strtod, non-integer input rejected
    - [build] fixed Kconfig pin defaults to match the board
    - [firmware] removed redundant encoder pull-up setup (done by PCNT driver)
    - [firmware] masked MQTT password on the settings screen
    - [firmware] pinned lwIP TCP/IP task to core 0
    - [build] replaced defconfig.bak with sdkconfig.defaults
    - [build] pinned component versions in idf_component.yml
    - [docs] updated README: ESP-IDF version,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
2026-10-23 Measurement fixes and V/I phase alignment tuning
    - [firmware] Replaced invalid ADC samples with the last good value of the expected channel, keeping V/I buffers in sync
    - [firmware] Removed ring buffer overflow warnings and the unused reset()
    - [firmware] Changed V/I alignment: V is delayed by whole samples only, the fractional part is applied to I by linear interpolation
    - [firmware] Merged LM358 shift constants into LM_SAMPLES_SHIFT and tuned it to 4.60 samples (phase error < 0.1° on resistive load)
    - [firmware] Added periodic energy counter save to NVS (every 0.1 kWh, at most once per minute)
    - [firmware] Replaced the runtime ADC sampling rate measurement with a compile-time constant fro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
2026-10-23 Grid frequency measured over a 1 s zero-crossing window
    - [firmware] Changed grid frequency measurement: rising zero crossings are timed on a continuous sample timeline across chunks, the frequency is taken over a 1 s window
    - [firmware] Increased grid frequency precision to 3 decimals on the display and in telemetry
    - [firmware] Moved the grid frequency bounds to DeviceSettings
2026-10-25 App fixes and refactoring
    - [firmware] fixed app shutdown: tasks are joined before shared queues and the console loop are disposed
    - [firmware] fixed IP event handler not unregistered on shutdown (event ID mismatch)
    - [firmware] fixed NVS float/double storage: std::bit_cast instead of pointer type punning
    - [firmware] fixed indicator task stack overflow: stack raised to 4096
    - [firmware] replaced the fixed settings PIN with the first 4 hex digits of the firmware ELF SHA256
    - [firmware] moved queue creation to the app, removed setup_indicator()
    - [build] removed obsolete credential entries from .gitignore
    - [docs] updated README: settings PIN and when settings lock again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
2026-10-25 PSRAM enabled for explicit allocations
    - [firmware] Enabled the 8 MB octal PSRAM, allocatable only through heap_caps_malloc() with MALLOC_CAP_SPIRAM
    - [firmware] Changed the heap metrics to report internal RAM only
    - [firmware] Raised the interrupt watchdog timeout to 800 ms, the IDF default with PSRAM
2026-10-26 Waveform recording, device health metrics and settings UI fixes
    - [firmware] Added waveform recording: raw V/I around grid frequency anomalies is published as binary to /metrics/waveform, buffers are allocated once in PSRAM
    - [firmware] Added the "Wave record" menu item: recording time is set with the encoder in 15 min steps, a push starts or stops it
    - [firmware] Added health metrics to device telemetry: ADC invalid samples and errors, despikes, zero-crossing resets and shifts, V/I ADC bias, Wi-Fi RSSI, Wi-Fi and MQTT disconnects, failed publishes
    - [firmware] Changed the MQTT period setting to whole seconds, set with the encoder
    - [firmware] Fixed telemetry stopping while the display was p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
2026-10-29 Version 1.6
    Crossings predicted from the fitted line, arcing bursts no longer restart the window
    - [firmware] Fixed window restarts after a displaced crossing: the next crossing is predicted from the least-squares line instead of the newest crossing
    - [firmware] Raised the rejects in a row before a window restart from 3 to 10, so arcing bursts are ridden through
    - [firmware] Fixed frequency needles after a window restart: the last frequency is held while the window refills, the filter is cleared only on a blackout
2026-11-05 Version 1.7: Frequency no longer locks on a wrong period after a blackout
    - [firmware] Fixed frequency stuck at 62.48 Hz after a blackout: until the window holds ZC_MIN_CROSSINGS crossings, each one must be the next cycle and any reject restarts the window
